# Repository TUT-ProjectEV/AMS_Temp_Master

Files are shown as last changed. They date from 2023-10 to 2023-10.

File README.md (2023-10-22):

# AMS_Temp_Master

## Overview
- AMSの温度測定基板
- スレーブ側
- 2023年度10月時点で使用

## Requirement
### Development
- Kicad 7.0
### Boards
- Arduino UNO
### Libraries

## Usage
- Arduinoマイコンボードとして使用
- I2C でスレーブ側からデータ取得
- CAN の使用方法はArduino UNO で CAN BUS Shield を使用した時と同じ

## Features

## Reference
- [AMS_Temp_Master](https://github.com/ST04-tkmr/KicadProjects_EVProject/tree/main/AMS_Temp_Master) より

## Author
- Takamura
    - [GitHub](https://github.com/ST04-tkmr)

## License
- Copyright (c) 2023 東京工科大学 ProjectEV [Released under the MIT license](https://github.com/TUT-ProjectEV/AMS_Temp_Master/blob/main/LICENSE)

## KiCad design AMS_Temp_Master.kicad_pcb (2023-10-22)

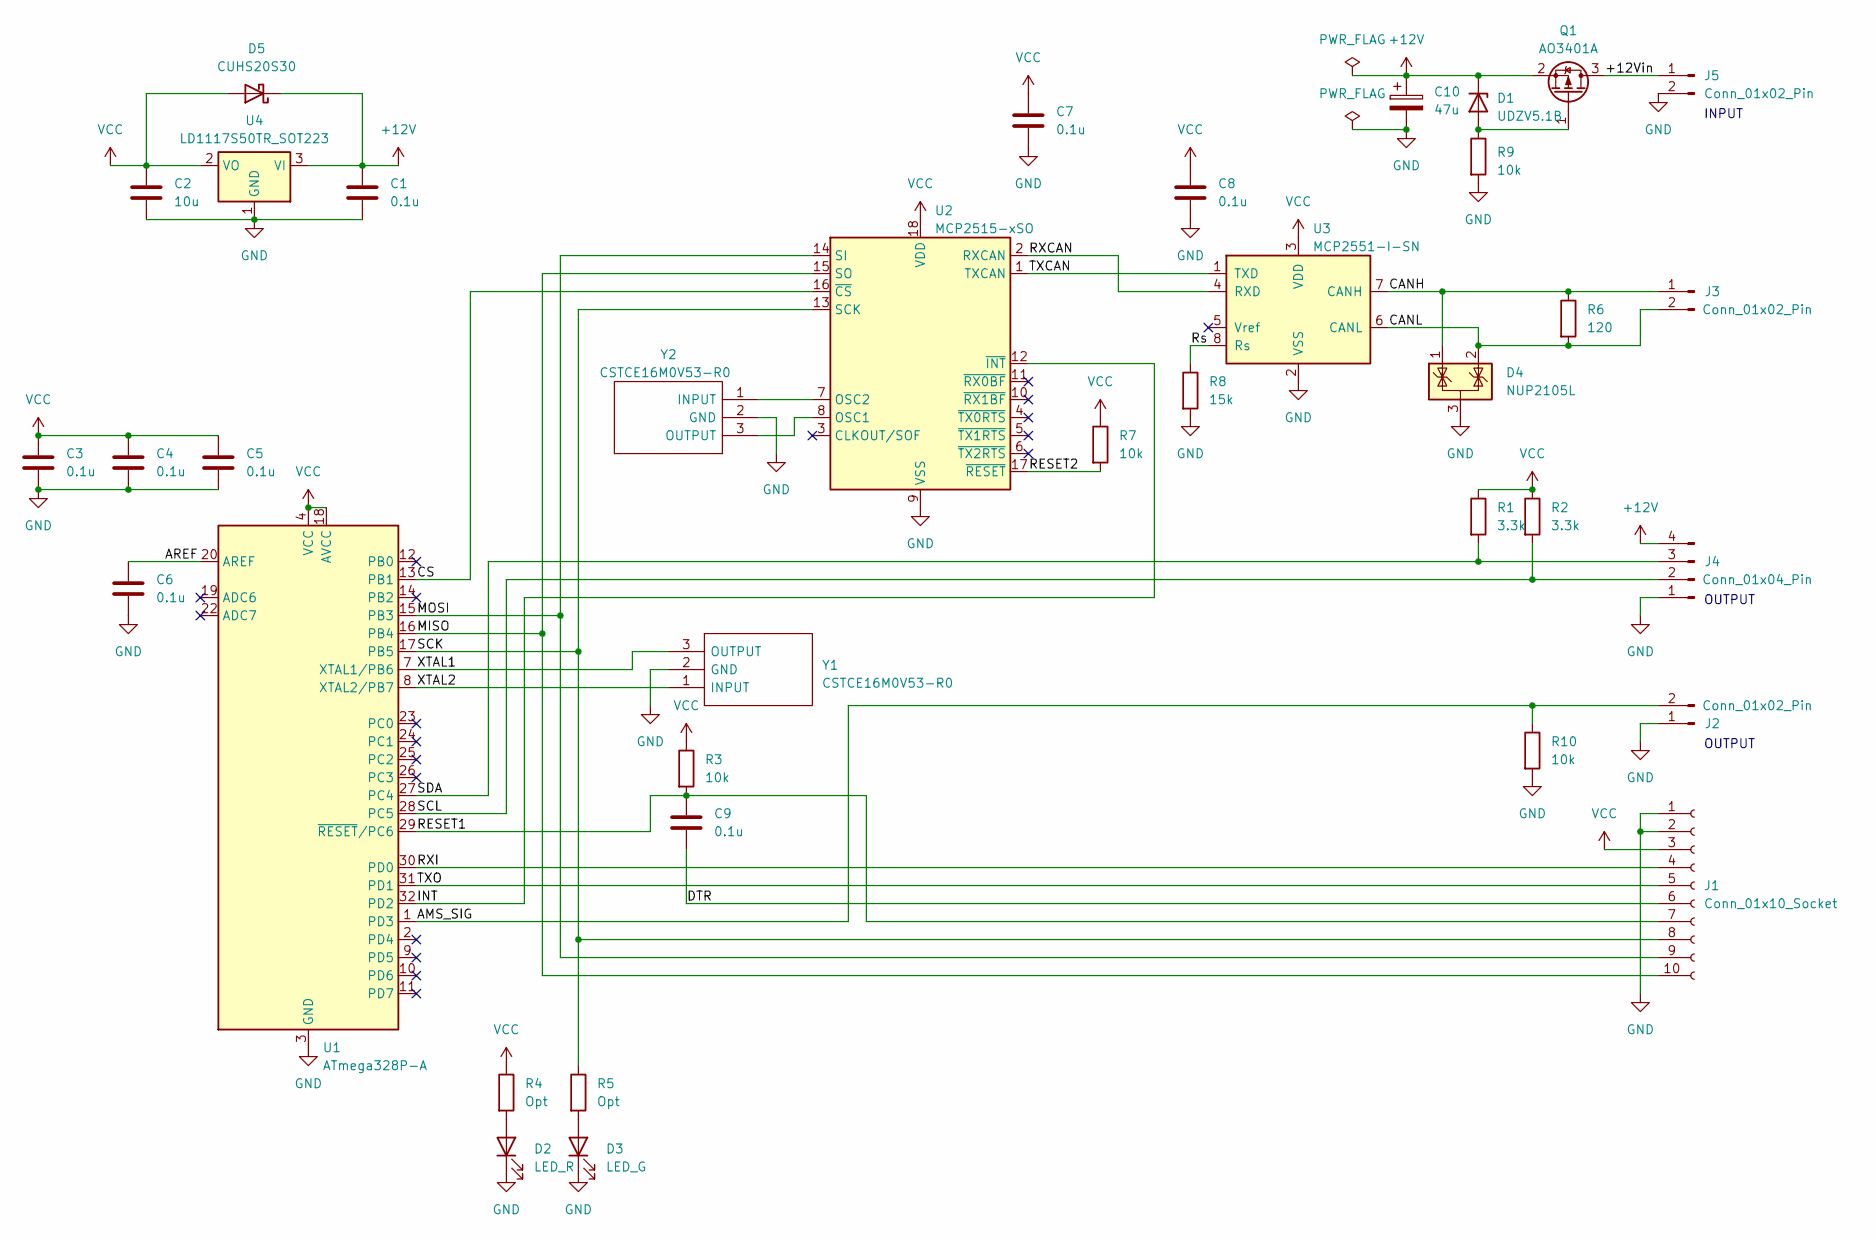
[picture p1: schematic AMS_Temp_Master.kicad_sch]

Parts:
C1, C3, C4, C5, C6, C7, C8, C9: 0.1u; C_0603_1608Metric
C2: 10u; C_0603_1608Metric
C10: 47u; CP_Elec_6.3x5.4_Nichicon
D1: UDZV5.1B; D_SOD-323_HandSoldering
D2: LED_R; LED_0603_1608Metric
D3: LED_G; LED_0603_1608Metric
D4: NUP2105L; SOT-23
D5: CUHS20S30; CUHS20S40H3F
J1: Conn_01x10_Socket; PinSocket_1x10_P2.54mm_Vertical
J2, J3, J5: Conn_01x02_Pin; JST_XH_S2B-XH-A_1x02_P2.50mm_Horizontal
J4: Conn_01x04_Pin; JST_XH_S4B-XH-A_1x04_P2.50mm_Horizontal
Q1: AO3401A; SOT-23
R1, R2: 3.3k; R_0603_1608Metric
R3, R7, R9, R10: 10k; R_0805_2012Metric
R4, R5: Opt; R_0603_1608Metric
R6: 120; R_0603_1608Metric
R8: 15k; R_0603_1608Metric
U1: ATmega328P-A; TQFP-32_7x7mm_P0.8mm
U2: MCP2515-xSO; SOIC-18W_7.5x11.6mm_P1.27mm
U3: MCP2551-I-SN; SOIC-8_3.9x4.9mm_P1.27mm
U4: LD1117S50TR_SOT223; SOT-223-3_TabPin2
Y1, Y2: CSTCE16M0V53-R0; CSTCE16M0V53R0; Manufacturer_Part_Number CSTCE16M0V53-R0; Mouser Part Number 81-CSTCE16M0V53-R0

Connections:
+12V: C1.1, C10.1, D1.1 (K), D5.1 (K), J4.4, Q1.2 (S), U4.3 (VI)
/+12Vin: J5.1, Q1.3 (D)
/AMS_SIG: J2.2, R10.1, U1.1 (PD3)
/AREF: C6.1, U1.20 (AREF)
/CANH: D4.1 (K), J3.1, R6.1, U3.7 (CANH)
/CANL: D4.2 (K), J3.2, R6.2, U3.6 (CANL)
/CS: U1.13 (PB1), U2.16 (~CS)
/DTR: C9.2, J1.6
/INT: U1.32 (PD2), U2.12 (~INT)
/MISO: J1.10, U1.16 (PB4), U2.15 (SO)
/MOSI: J1.9, U1.15 (PB3), U2.14 (SI)
/RESET1: C9.1, J1.7, R3.2, U1.29 (~RESET/PC6)
/RESET2: R7.2, U2.17 (~RESET)
/RXCAN: U2.2 (RXCAN), U3.4 (RXD)
/RXI: J1.4, U1.30 (PD0)
/Rs: R8.1, U3.8 (Rs)
/SCK: J1.8, R5.1, U1.17 (PB5), U2.13 (SCK)
/SCL: J4.2, R2.2, U1.28 (PC5)
/SDA: J4.3, R1.2, U1.27 (PC4)
/TXCAN: U2.1 (TXCAN), U3.1 (TXD)
/TXO: J1.5, U1.31 (PD1)
/XTAL1: U1.7 (XTAL1/PB6), Y1.3 (OUTPUT)
/XTAL2: U1.8 (XTAL2/PB7), Y1.1 (INPUT)
GND: C1.2, C2.2, C3.2, C4.2, C5.2, C6.2, C7.2, C8.2, C10.2, D2.1 (K), D3.1 (K), D4.3 (A), J1.1, J1.2, J2.1, J4.1, J5.2, R8.2, R9.2, R10.2, U1.3 (GND), U1.5 (GND), U1.21 (GND), U2.9 (VSS), U3.2 (VSS), U4.1 (GND), Y1.2 (GND), Y2.2 (GND)
unnamed: D1.2 (A), Q1.1 (G), R9.1
unnamed: D2.2 (A), R4.2
unnamed: D3.2 (A), R5.2
unnamed: U2.8 (OSC1), Y2.3 (OUTPUT)
unnamed: U2.7 (OSC2), Y2.1 (INPUT)
VCC: C2.1, C3.1, C4.1, C5.1, C7.1, C8.1, D5.2 (A), J1.3, R1.1, R2.1, R3.1, R4.1, R7.1, U1.4 (VCC), U1.6 (VCC), U1.18 (AVCC), U2.18 (VDD), U3.3 (VDD), U4.2 (VO)

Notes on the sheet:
OUTPUT
INPUT

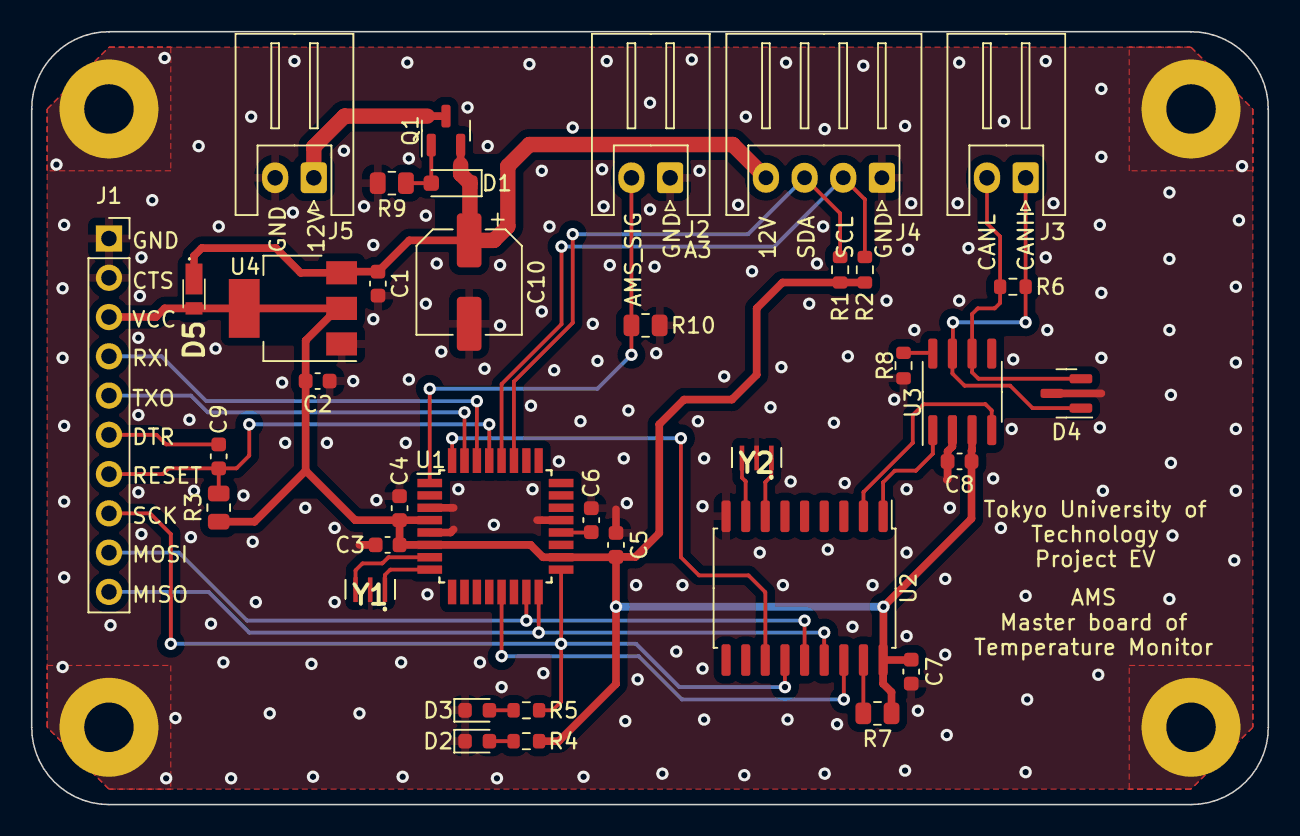
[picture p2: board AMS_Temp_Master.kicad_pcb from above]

Board: 2 copper layers, 80.0 x 50.0 mm, 37 parts (0 on the bottom side), 30 nets.
